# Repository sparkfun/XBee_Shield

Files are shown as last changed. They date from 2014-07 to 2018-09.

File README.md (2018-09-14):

XBee Shield
===========

<table class="table table-hover table-striped table-bordered">
  <tr align="center">
   <td><a href="https://www.sparkfun.com/products/12847">XBee Shield</a></td>
   <td><a href="https://www.sparkfun.com/products/13197">SparkFun XBee Shield Kit</a></td>
  </tr>
  <tr align="center">
    <td>XBee Shield [<a href="https://www.sparkfun.com/products/12847">WRL-12847</a>]</td>
    <td>SparkFun XBee Wireless Kit [<a href="https://www.sparkfun.com/products/13197">KIT-13197</a>]</td>
  </tr>
</table>

This shield mates directly with any dev board that has an Arduino standard footprint and equips it with the wireless
communication capabilities using the popular XBee modules. 

Repository Contents
-------------------
* **/Hardware** - All Eagle design files (.brd, .sch)
* **/Production** - Test bed files and production panel files

Documentation
--------------
* **[Exploring XBees and XCTU](https://learn.sparkfun.com/tutorials/exploring-xbees-and-xctu)** - Getting started with the XBee software and configuring XBees.
* **[Hookup Guide](https://learn.sparkfun.com/tutorials/xbee-shield-hookup-guide)** - Basic hookup guide for the XBee Shield for Arduinos.

Product Versions
----------------
* [WRL-12847](https://www.sparkfun.com/products/12847)- XBee Shield
* [KIT-13197](https://www.sparkfun.com/products/13197)- XBee Wireless Kit with XBee Series 1 Modules

Version History
---------------
* [v14](https://www.sparkfun.com/products/10854) Version 1.4. 

License Information
-------------------
License Information
-------------------

This product is _**open source**_! 

Please review the LICENSE.md file for license information. 

If you have any questions or concerns on licensing, please contact techsupport@sparkfun.com.

Distributed as-is; no warranty is given.

- Your friends at SparkFun.

_<COLLABORATION CREDIT>_

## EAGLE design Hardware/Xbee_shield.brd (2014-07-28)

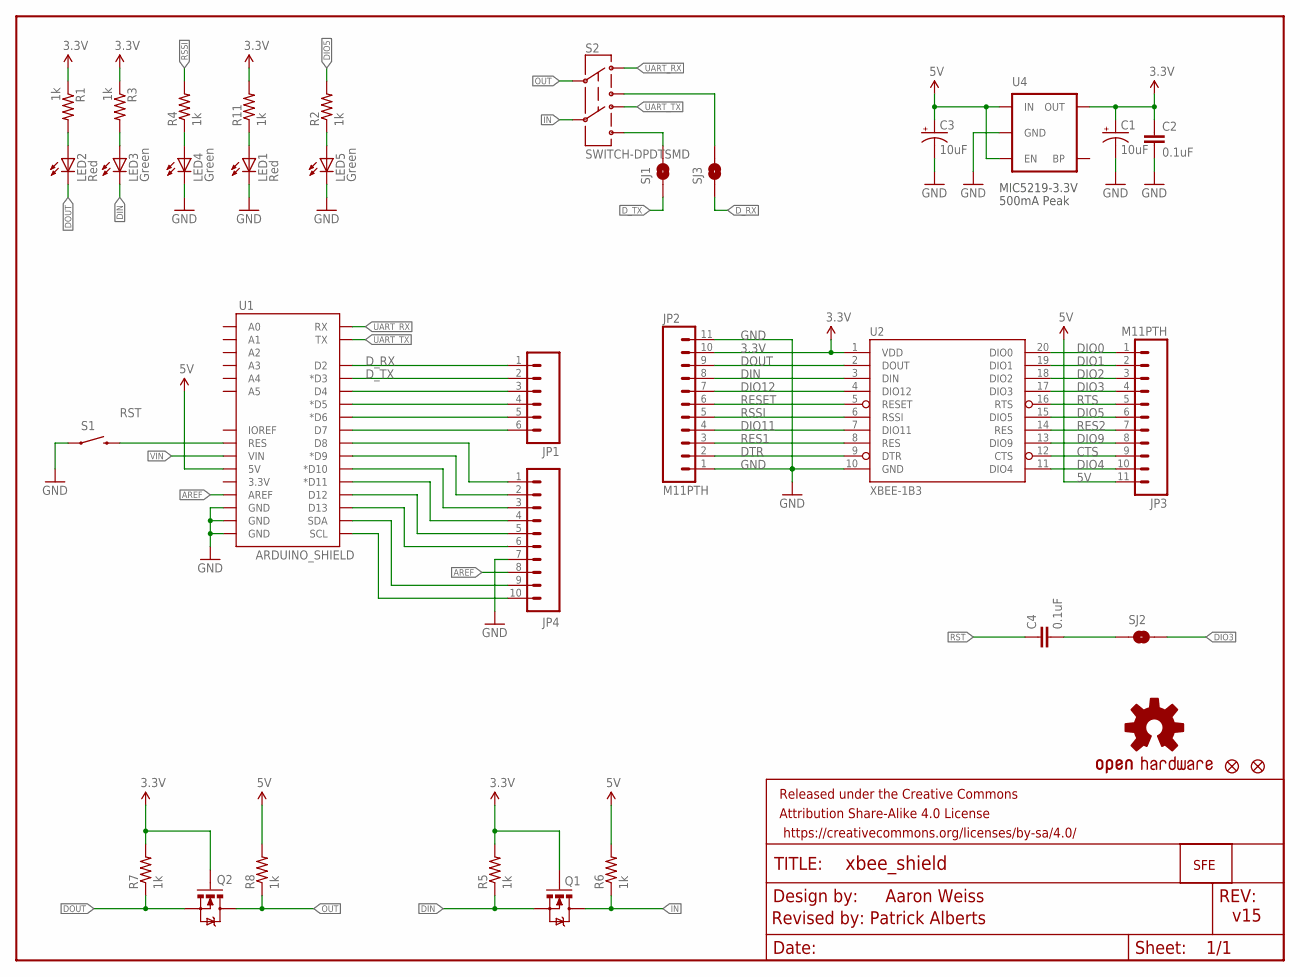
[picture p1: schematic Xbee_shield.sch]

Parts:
C1, C3: 10uF; EIA3216
C2, C4: 0.1uF; 0603-CAP
FRAME1: FRAME-LETTER; CREATIVE_COMMONS
JP1: M06SIP; 1X06
JP2, JP3: M11PTH; 1X11
JP4: M10"; 1X10
JP5, JP6: FIDUCIAL1X2; FIDUCIAL-1X2
JP7: LOGO-SFENEW; SFE-NEW-WEBLOGO
LED1, LED2: Red; LED-0603
LED3, LED4, LED5: Green; LED-0603
Q1, Q2: MOSFET-NCHANNELSMD; SOT23-3
R1, R2, R3, R4, R5, R6, R7, R8, R11: 1k; 0603-RES
S1: SWITCH-MOMENTARY-2SMD; TACTILE_SWITCH_SMD
S2: SWITCH-DPDTSMD; AYZ0202
SJ1: D_TX; SJ_2S
SJ2: SOLDERJUMPERTRACE; SJ_2S-TRACE
SJ3: D_RX; SJ_2S
U1: ARDUINO_SHIELD; UNO_R3_SHIELD
U2: XBEE-1B3; XBEE-SMD
U4: V_REG_LDOSMD; SOT23-5
U$8: OSHW-LOGOS; OSHW-LOGO-S

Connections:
3.3V: C1.A (+), C2.1, JP2.10, Q1.1 (G), Q2.1 (G), R1.1, R3.1, R5.2, R7.2, R11.2, U2.1 (VDD), U4.5 (OUT)
5V: C3.A (+), JP3.11, R6.2, R8.2, U1.5V, U4.1 (IN), U4.3 (EN)
AREF: JP4.8, U1.AREF
CTS: JP3.9, U2.12 (CTS)
DIN: JP2.8, LED3.C, Q1.2 (S), R5.1, U2.3 (DIN)
DIO0: JP3.1, U2.20 (DIO0)
DIO1: JP3.2, U2.19 (DIO1)
DIO2: JP3.3, U2.18 (DIO2)
DIO3: JP3.4, SJ2.2, U2.17 (DIO3)
DIO4: JP3.10, U2.11 (DIO4)
DIO5: JP3.6, R2.2, U2.15 (DIO5)
DIO9: JP3.8, U2.13 (DIO9)
DIO11: JP2.4, U2.7 (DIO11)
DIO12: JP2.7, U2.4 (DIO12)
DOUT: JP2.9, LED2.C, Q2.2 (S), R7.1, U2.2 (DOUT)
DTR: JP2.2, U2.9 (DTR)
D_RX: JP1.1, SJ3.1, U1.D2
D_TX: JP1.2, SJ1.1, U1.D3 (*D3)
GND: C1.C (-), C2.2, C3.C (-), JP2.1, JP2.11, JP4.7, LED1.C, LED4.C, LED5.C, S1.1, U1.GND@0 (GND), U1.GND@1 (GND), U1.GND@2 (GND), U2.10 (GND), U4.2 (GND)
IN: Q1.3 (D), R6.1, S2.5
unnamed: LED2.A, R1.2
unnamed: LED4.A, R4.1
unnamed: JP4.6, U1.D13
unnamed: LED3.A, R3.2
unnamed: C4.2, SJ2.1
unnamed: JP4.9, U1.SDA
unnamed: JP4.10, U1.SCL
unnamed: JP4.1, U1.D8
unnamed: JP4.2, U1.D9 (*D9)
unnamed: JP4.3, U1.D10 (*D10)
unnamed: LED1.A, R11.1
unnamed: JP4.4, U1.D11 (*D11)
unnamed: JP4.5, U1.D12
unnamed: LED5.A, R2.1
unnamed: S2.6, SJ1.2
unnamed: S2.3, SJ3.2
unnamed: JP1.3, U1.D4
unnamed: JP1.4, U1.D5 (*D5)
unnamed: JP1.5, U1.D6 (*D6)
unnamed: JP1.6, U1.D7
OUT: Q2.3 (D), R8.1, S2.2
RES1: JP2.3, U2.8 (RES)
RES2: JP3.7, U2.14 (RES)
RESET: JP2.6, U2.5 (RESET)
RSSI: JP2.5, R4.2, U2.6 (RSSI)
RST: C4.1, S1.3 (2), U1.RES
RTS: JP3.5, U2.16 (RTS)
UART_RX: S2.1, U1.RX
UART_TX: S2.4, U1.TX
VIN: U1.VIN

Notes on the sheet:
500mA Peak
MIC5219-3.3V
Aaron Weiss
v15
Revised by: Patrick Alberts

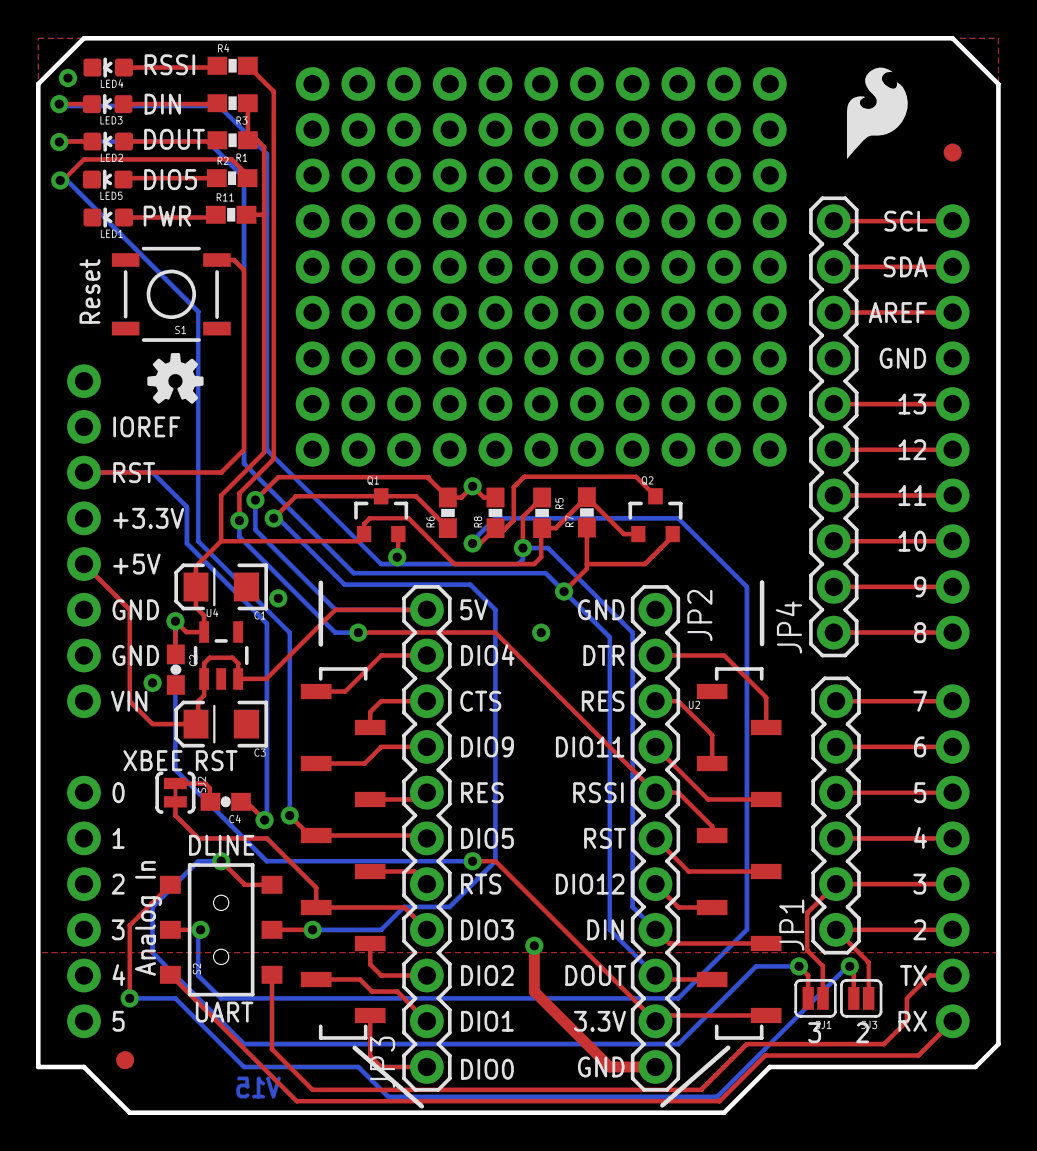
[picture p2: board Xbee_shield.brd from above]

Board: 2 copper layers, 53.3 x 59.7 mm, 38 parts (1 on the bottom side), 49 nets.

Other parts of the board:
U$1: SFE_LOGO_FLAME_.2

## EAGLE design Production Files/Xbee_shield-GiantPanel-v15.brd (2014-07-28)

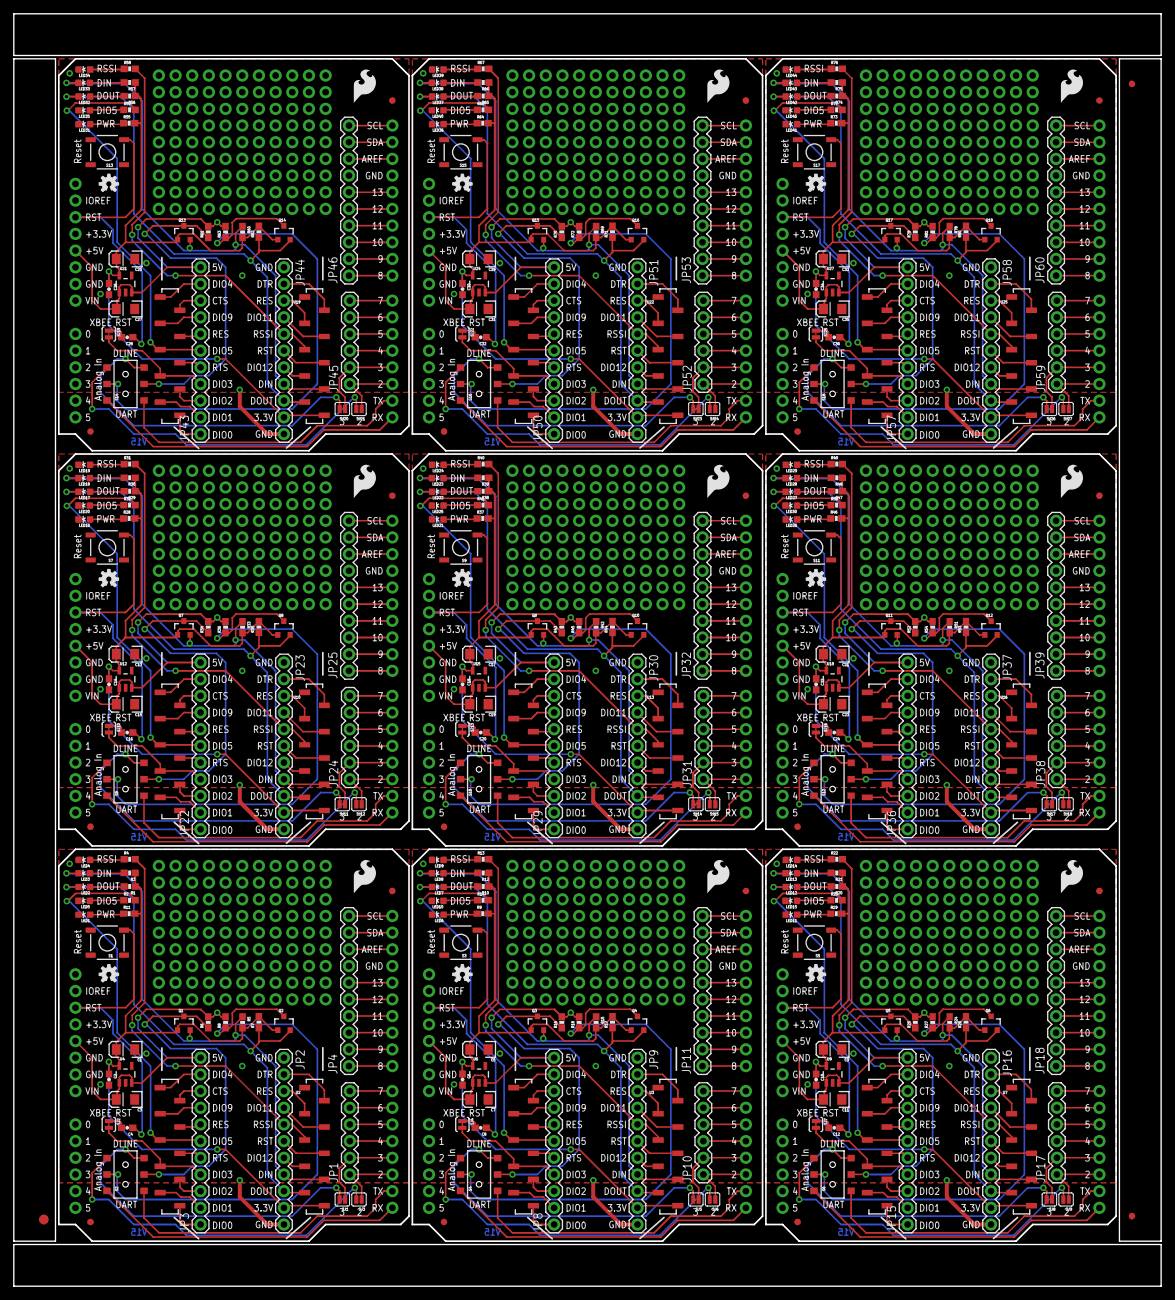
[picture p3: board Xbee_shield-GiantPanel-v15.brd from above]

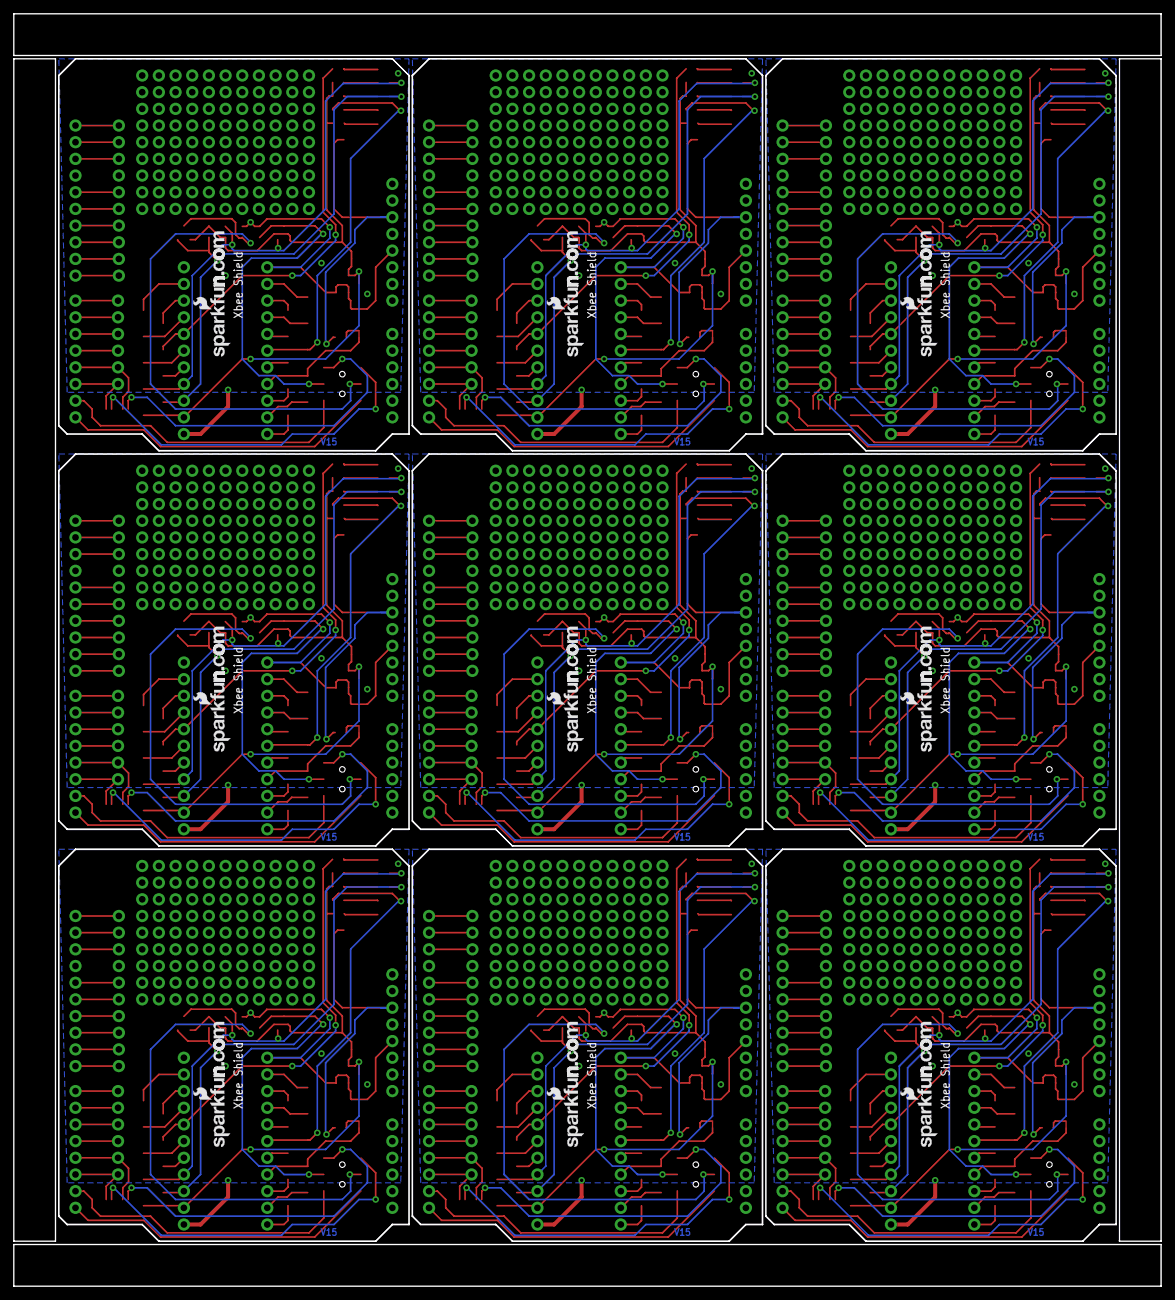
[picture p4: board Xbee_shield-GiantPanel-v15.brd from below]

Board: 2 copper layers, 174.8 x 193.8 mm, 336 parts (9 on the bottom side), 441 nets.

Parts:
C1, C3, C5, C7, C9, C11, C13, C15, C17, C19, C21, C23, C25, C27, C29, C31, C33, C35: 10uF; EIA3216
C2, C4, C6, C8, C10, C12, C14, C16, C18, C20, C22, C24, C26, C28, C30, C32, C34, C36: 0.1uF; 0603-CAP
E$1: FIDUCIAL-1.5X3
E$4, E$5: FIDUCIAL-1X2
JP1, JP10, JP17, JP24, JP31, JP38, JP45, JP52, JP59: 1X06
JP2, JP3, JP8, JP9, JP15, JP16, JP22, JP23, JP29, JP30, JP36, JP37, JP43, JP44, JP50, JP51, JP57, JP58: M11PTH; 1X11
JP4, JP11, JP18, JP25, JP32, JP39, JP46, JP53, JP60: 1X10
JP5, JP6, JP12, JP13, JP19, JP20, JP26, JP27, JP33, JP34, JP40, JP41, JP47, JP48, JP54, JP55, JP61, JP62: FIDUCIAL1X2; FIDUCIAL-1X2
JP7, JP14, JP21, JP28, JP35, JP42, JP49, JP56, JP63: LOGO-SFENEW; SFE-NEW-WEBLOGO
LED1, LED2, LED6, LED7, LED11, LED12, LED16, LED17, LED21, LED22, LED26, LED27, LED31, LED32, LED36, LED37, LED41, LED42: Red; LED-0603
LED3, LED4, LED5, LED8, LED9, LED10, LED13, LED14, LED15, LED18, LED19, LED20, LED23, LED24, LED25, LED28, LED29, LED30, LED33, LED34, LED35, LED38, LED39, LED40, LED43, LED44, LED45: Green; LED-0603
Q1, Q2, Q3, Q4, Q5, Q6, Q7, Q8, Q9, Q10, Q11, Q12, Q13, Q14, Q15, Q16, Q17, Q18: MOSFET-NCHANNELSMD; SOT23-3
R1, R2, R3, R4, R5, R6, R7, R8, R9, R10, R11, R12, R13, R14, R15, R16, R17, R18, R19, R20, R21, R22, R23, R24, R25, R26, R27, R28, R29, R30, R31, R32, R33, R34, R35, R36, R37, R38, R39, R40, R41, R42, R43, R44, R45, R46, R47, R48, R49, R50, R51, R52, R53, R54, R55, R56, R57, R58, R59, R60, R61, R62, R63, R64, R65, R66, R67, R68, R69, R70, R71, R72, R73, R74, R75, R76, R77, R78, R79, R80, R81: 1k; 0603-RES
S1, S3, S5, S7, S9, S11, S13, S15, S17: SWITCH-MOMENTARY-2SMD; TACTILE_SWITCH_SMD
S2, S4, S6, S8, S10, S12, S14, S16, S18: SWITCH-DPDTSMD; AYZ0202
SJ1, SJ5, SJ8, SJ11, SJ14, SJ17, SJ20, SJ23, SJ26: D_TX; SJ_2S
SJ2, SJ4, SJ7, SJ10, SJ13, SJ16, SJ19, SJ22, SJ25: SOLDERJUMPERTRACE; SJ_2S-TRACE
SJ3, SJ6, SJ9, SJ12, SJ15, SJ18, SJ21, SJ24, SJ27: D_RX; SJ_2S
U1, U5, U8, U11, U14, U17, U20, U23, U26: ARDUINO_SHIELD; UNO_R3_SHIELD
U2, U3, U7, U10, U13, U16, U19, U22, U25: XBEE-1B3; XBEE-SMD
U4, U6, U9, U12, U15, U18, U21, U24, U27: V_REG_LDOSMD; SOT23-5
U$1, U$3, U$5, U$7, U$10, U$12, U$14, U$16, U$18: SFE_LOGO_FLAME_.2
U$2, U$4, U$6, U$8, U$9, U$11, U$13, U$15, U$17: OSHW-LOGOS; OSHW-LOGO-S

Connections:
3.3V: C1.A, C2.1, JP2.10, Q1.1, Q2.1, R1.1, R3.1, R5.2, R7.2, R11.2, U2.1, U4.5
3.3V1: C5.A, C6.1, JP9.10, Q3.1, Q4.1, R9.2, R10.1, R12.1, R15.2, R17.2, U3.1, U6.5
3.3V2: C9.A, C10.1, JP16.10, Q5.1, Q6.1, R19.2, R20.1, R21.1, R24.2, R26.2, U7.1, U9.5
3.3V3: C13.A, C14.1, JP23.10, Q7.1, Q8.1, R28.2, R29.1, R30.1, R33.2, R35.2, U10.1, U12.5
3.3V4: C17.A, C18.1, JP30.10, Q9.1, Q10.1, R37.2, R38.1, R39.1, R42.2, R44.2, U13.1, U15.5
3.3V5: C21.A, C22.1, JP37.10, Q11.1, Q12.1, R46.2, R47.1, R48.1, R51.2, R53.2, U16.1, U18.5
3.3V6: C25.A, C26.1, JP44.10, Q13.1, Q14.1, R55.2, R56.1, R57.1, R60.2, R62.2, U19.1, U21.5
3.3V7: C29.A, C30.1, JP51.10, Q15.1, Q16.1, R64.2, R65.1, R66.1, R69.2, R71.2, U22.1, U24.5
3.3V8: C33.A, C34.1, JP58.10, Q17.1, Q18.1, R73.2, R74.1, R75.1, R78.2, R80.2, U25.1, U27.5
5V: C3.A, JP3.11, R6.2, R8.2, U1.5V, U4.1, U4.3
5V1: C7.A, JP8.11, R16.2, R18.2, U5.5V, U6.1, U6.3
5V2: C11.A, JP15.11, R25.2, R27.2, U8.5V, U9.1, U9.3
5V3: C15.A, JP22.11, R34.2, R36.2, U11.5V, U12.1, U12.3
5V4: C19.A, JP29.11, R43.2, R45.2, U14.5V, U15.1, U15.3
5V5: C23.A, JP36.11, R52.2, R54.2, U17.5V, U18.1, U18.3
5V6: C27.A, JP43.11, R61.2, R63.2, U20.5V, U21.1, U21.3
5V7: C31.A, JP50.11, R70.2, R72.2, U23.5V, U24.1, U24.3
5V8: C35.A, JP57.11, R79.2, R81.2, U26.5V, U27.1, U27.3
AREF: JP4.8, U1.AREF
AREF1: JP11.8, U5.AREF
AREF2: JP18.8, U8.AREF
AREF3: JP25.8, U11.AREF
AREF4: JP32.8, U14.AREF
AREF5: JP39.8, U17.AREF
AREF6: JP46.8, U20.AREF
AREF7: JP53.8, U23.AREF
AREF8: JP60.8, U26.AREF
CTS: JP3.9, U2.12
CTS1: JP8.9, U3.12
CTS2: JP15.9, U7.12
CTS3: JP22.9, U10.12
CTS4: JP29.9, U13.12
CTS5: JP36.9, U16.12
CTS6: JP43.9, U19.12
CTS7: JP50.9, U22.12
CTS8: JP57.9, U25.12
DIN: JP2.8, LED3.C, Q1.2, R5.1, U2.3
DIN1: JP9.8, LED8.C, Q3.2, R15.1, U3.3
DIN2: JP16.8, LED13.C, Q5.2, R24.1, U7.3
DIN3: JP23.8, LED18.C, Q7.2, R33.1, U10.3
DIN4: JP30.8, LED23.C, Q9.2, R42.1, U13.3
DIN5: JP37.8, LED28.C, Q11.2, R51.1, U16.3
DIN6: JP44.8, LED33.C, Q13.2, R60.1, U19.3
DIN7: JP51.8, LED38.C, Q15.2, R69.1, U22.3
DIN8: JP58.8, LED43.C, Q17.2, R78.1, U25.3
DIO0: JP3.1, U2.20
DIO1: JP3.2, U2.19
DIO2: JP3.3, U2.18
DIO3: JP3.4, SJ2.2, U2.17
DIO4: JP3.10, U2.11
DIO5: JP3.6, R2.2, U2.15
DIO6: JP8.10, U3.11
DIO7: JP8.8, U3.13
DIO8: JP8.6, R14.2, U3.15
DIO9: JP3.8, U2.13
DIO10: JP8.4, SJ4.2, U3.17
DIO11: JP2.4, U2.7
DIO12: JP2.7, U2.4
DIO13: JP8.3, U3.18
DIO14: JP8.2, U3.19
DIO15: JP8.1, U3.20
DIO16: JP9.4, U3.7
DIO17: JP9.7, U3.4
DIO18: JP15.10, U7.11
DIO19: JP15.8, U7.13
DIO20: JP15.6, R23.2, U7.15
DIO21: JP15.4, SJ7.2, U7.17
DIO22: JP15.3, U7.18
DIO23: JP15.2, U7.19
DIO24: JP15.1, U7.20
DIO25: JP16.4, U7.7
DIO26: JP16.7, U7.4
DIO27: JP22.10, U10.11
DIO28: JP22.8, U10.13
DIO29: JP22.6, R32.2, U10.15
DIO30: JP22.4, SJ10.2, U10.17
DIO31: JP22.3, U10.18
DIO32: JP22.2, U10.19
DIO33: JP22.1, U10.20
DIO34: JP23.4, U10.7
DIO35: JP23.7, U10.4
DIO36: JP29.10, U13.11
DIO37: JP29.8, U13.13
DIO38: JP29.6, R41.2, U13.15
DIO39: JP29.4, SJ13.2, U13.17
DIO40: JP29.3, U13.18
DIO41: JP29.2, U13.19
DIO42: JP29.1, U13.20
DIO43: JP30.4, U13.7
DIO44: JP30.7, U13.4
DIO45: JP36.10, U16.11
DIO46: JP36.8, U16.13
DIO47: JP36.6, R50.2, U16.15
DIO48: JP36.4, SJ16.2, U16.17
DIO49: JP36.3, U16.18
DIO50: JP36.2, U16.19
DIO51: JP36.1, U16.20
DIO52: JP37.4, U16.7
DIO53: JP37.7, U16.4
DIO54: JP43.10, U19.11
DIO55: JP43.8, U19.13
DIO56: JP43.6, R59.2, U19.15
DIO57: JP43.4, SJ19.2, U19.17
DIO58: JP43.3, U19.18
DIO59: JP43.2, U19.19
DIO60: JP43.1, U19.20
DIO61: JP44.4, U19.7
DIO62: JP44.7, U19.4
DIO63: JP50.10, U22.11
DIO64: JP50.8, U22.13
DIO65: JP50.6, R68.2, U22.15
DIO66: JP50.4, SJ22.2, U22.17
DIO67: JP50.3, U22.18
DIO68: JP50.2, U22.19
DIO69: JP50.1, U22.20
DIO70: JP51.4, U22.7
DIO71: JP51.7, U22.4
DIO72: JP57.10, U25.11
DIO73: JP57.8, U25.13
DIO74: JP57.6, R77.2, U25.15
DIO75: JP57.4, SJ25.2, U25.17
DIO76: JP57.3, U25.18
DIO77: JP57.2, U25.19
DIO78: JP57.1, U25.20
DIO79: JP58.4, U25.7
DIO80: JP58.7, U25.4
DOUT: JP2.9, LED2.C, Q2.2, R7.1, U2.2
DOUT1: JP9.9, LED7.C, Q4.2, R17.1, U3.2
DOUT2: JP16.9, LED12.C, Q6.2, R26.1, U7.2
DOUT3: JP23.9, LED17.C, Q8.2, R35.1, U10.2
DOUT4: JP30.9, LED22.C, Q10.2, R44.1, U13.2
DOUT5: JP37.9, LED27.C, Q12.2, R53.1, U16.2
DOUT6: JP44.9, LED32.C, Q14.2, R62.1, U19.2
DOUT7: JP51.9, LED37.C, Q16.2, R71.1, U22.2
DOUT8: JP58.9, LED42.C, Q18.2, R80.1, U25.2
DTR: JP2.2, U2.9
DTR1: JP9.2, U3.9
DTR2: JP16.2, U7.9
DTR3: JP23.2, U10.9
DTR4: JP30.2, U13.9
DTR5: JP37.2, U16.9
DTR6: JP44.2, U19.9
DTR7: JP51.2, U22.9
DTR8: JP58.2, U25.9
D_RX: JP1.1, SJ3.1, U1.D2
D_RX1: JP10.1, SJ6.1, U5.D2
D_RX2: JP17.1, SJ9.1, U8.D2
D_RX3: JP24.1, SJ12.1, U11.D2
D_RX4: JP31.1, SJ15.1, U14.D2
D_RX5: JP38.1, SJ18.1, U17.D2
D_RX6: JP45.1, SJ21.1, U20.D2
D_RX7: JP52.1, SJ24.1, U23.D2
D_RX8: JP59.1, SJ27.1, U26.D2
D_TX: JP1.2, SJ1.1, U1.D3
D_TX1: JP10.2, SJ5.1, U5.D3
D_TX2: JP17.2, SJ8.1, U8.D3
D_TX3: JP24.2, SJ11.1, U11.D3
D_TX4: JP31.2, SJ14.1, U14.D3
D_TX5: JP38.2, SJ17.1, U17.D3
D_TX6: JP45.2, SJ20.1, U20.D3
D_TX7: JP52.2, SJ23.1, U23.D3
D_TX8: JP59.2, SJ26.1, U26.D3
GND: C1.C, C2.2, C3.C, JP2.1, JP2.11, JP4.7, LED1.C, LED4.C, LED5.C, S1.1, U1.GND@0, U1.GND@1, U1.GND@2, U2.10, U4.2
GND1: C5.C, C6.2, C7.C, JP9.1, JP9.11, JP11.7, LED6.C, LED9.C, LED10.C, S3.1, U3.10, U5.GND@0, U5.GND@1, U5.GND@2, U6.2
GND2: C9.C, C10.2, C11.C, JP16.1, JP16.11, JP18.7, LED11.C, LED14.C, LED15.C, S5.1, U7.10, U8.GND@0, U8.GND@1, U8.GND@2, U9.2
GND3: C13.C, C14.2, C15.C, JP23.1, JP23.11, JP25.7, LED16.C, LED19.C, LED20.C, S7.1, U10.10, U11.GND@0, U11.GND@1, U11.GND@2, U12.2
GND4: C17.C, C18.2, C19.C, JP30.1, JP30.11, JP32.7, LED21.C, LED24.C, LED25.C, S9.1, U13.10, U14.GND@0, U14.GND@1, U14.GND@2, U15.2
GND5: C21.C, C22.2, C23.C, JP37.1, JP37.11, JP39.7, LED26.C, LED29.C, LED30.C, S11.1, U16.10, U17.GND@0, U17.GND@1, U17.GND@2, U18.2
GND6: C25.C, C26.2, C27.C, JP44.1, JP44.11, JP46.7, LED31.C, LED34.C, LED35.C, S13.1, U19.10, U20.GND@0, U20.GND@1, U20.GND@2, U21.2
GND7: C29.C, C30.2, C31.C, JP51.1, JP51.11, JP53.7, LED36.C, LED39.C, LED40.C, S15.1, U22.10, U23.GND@0, U23.GND@1, U23.GND@2, U24.2
GND8: C33.C, C34.2, C35.C, JP58.1, JP58.11, JP60.7, LED41.C, LED44.C, LED45.C, S17.1, U25.10, U26.GND@0, U26.GND@1, U26.GND@2, U27.2
IN: Q1.3, R6.1, S2.5
IN1: Q3.3, R16.1, S4.5
IN2: Q5.3, R25.1, S6.5
IN3: Q7.3, R34.1, S8.5
IN4: Q9.3, R43.1, S10.5
IN5: Q11.3, R52.1, S12.5
IN6: Q13.3, R61.1, S14.5
IN7: Q15.3, R70.1, S16.5
IN8: Q17.3, R79.1, S18.5
unnamed: LED2.A, R1.2
unnamed: LED4.A, R4.1
unnamed: JP4.6, U1.D13
unnamed: LED3.A, R3.2
unnamed: C4.2, SJ2.1
unnamed: JP4.9, U1.SDA
unnamed: JP4.10, U1.SCL
unnamed: LED6.A, R9.1
unnamed: LED7.A, R10.2
unnamed: LED8.A, R12.2
unnamed: LED9.A, R13.1
unnamed: C8.2, SJ4.1
unnamed: JP4.1, U1.D8
unnamed: JP4.2, U1.D9
unnamed: JP4.3, U1.D10
unnamed: LED1.A, R11.1
unnamed: JP4.4, U1.D11
unnamed: JP4.5, U1.D12
unnamed: LED5.A, R2.1
unnamed: S2.6, SJ1.2
unnamed: S2.3, SJ3.2
unnamed: JP1.3, U1.D4
unnamed: JP1.4, U1.D5
unnamed: JP1.5, U1.D6
unnamed: JP1.6, U1.D7
unnamed: LED10.A, R14.1
unnamed: S4.6, SJ5.2
unnamed: S4.3, SJ6.2
unnamed: JP10.3, U5.D4
unnamed: JP10.4, U5.D5
unnamed: JP10.5, U5.D6
unnamed: JP10.6, U5.D7
unnamed: JP11.1, U5.D8
unnamed: JP11.2, U5.D9
unnamed: JP11.3, U5.D10
unnamed: JP11.4, U5.D11
unnamed: JP11.5, U5.D12
unnamed: JP11.6, U5.D13
unnamed: JP11.9, U5.SDA
unnamed: JP11.10, U5.SCL
unnamed: LED11.A, R19.1
unnamed: LED12.A, R20.2
unnamed: LED13.A, R21.2
unnamed: LED14.A, R22.1
unnamed: C12.2, SJ7.1
unnamed: LED15.A, R23.1
unnamed: S6.6, SJ8.2
unnamed: S6.3, SJ9.2
unnamed: JP17.3, U8.D4
unnamed: JP17.4, U8.D5
unnamed: JP17.5, U8.D6
unnamed: JP17.6, U8.D7
unnamed: JP18.1, U8.D8
unnamed: JP18.2, U8.D9
unnamed: JP18.3, U8.D10
unnamed: JP18.4, U8.D11
unnamed: JP18.5, U8.D12
unnamed: JP18.6, U8.D13
unnamed: JP18.9, U8.SDA
unnamed: JP18.10, U8.SCL
unnamed: LED16.A, R28.1
unnamed: LED17.A, R29.2
unnamed: LED18.A, R30.2
unnamed: LED19.A, R31.1
unnamed: C16.2, SJ10.1
unnamed: LED20.A, R32.1
unnamed: S8.6, SJ11.2
unnamed: S8.3, SJ12.2
unnamed: JP24.3, U11.D4
unnamed: JP24.4, U11.D5
unnamed: JP24.5, U11.D6
unnamed: JP24.6, U11.D7
unnamed: JP25.1, U11.D8
unnamed: JP25.2, U11.D9
unnamed: JP25.3, U11.D10
unnamed: JP25.4, U11.D11
unnamed: JP25.5, U11.D12
unnamed: JP25.6, U11.D13
unnamed: JP25.9, U11.SDA
unnamed: JP25.10, U11.SCL
unnamed: LED21.A, R37.1
unnamed: LED22.A, R38.2
unnamed: LED23.A, R39.2
unnamed: LED24.A, R40.1
unnamed: C20.2, SJ13.1
unnamed: LED25.A, R41.1
unnamed: S10.6, SJ14.2
unnamed: S10.3, SJ15.2
unnamed: JP31.3, U14.D4
unnamed: JP31.4, U14.D5
unnamed: JP31.5, U14.D6
unnamed: JP31.6, U14.D7
unnamed: JP32.1, U14.D8
unnamed: JP32.2, U14.D9
unnamed: JP32.3, U14.D10
unnamed: JP32.4, U14.D11
unnamed: JP32.5, U14.D12
unnamed: JP32.6, U14.D13
unnamed: JP32.9, U14.SDA
unnamed: JP32.10, U14.SCL
unnamed: LED26.A, R46.1
unnamed: LED27.A, R47.2
unnamed: LED28.A, R48.2
unnamed: LED29.A, R49.1
unnamed: C24.2, SJ16.1
unnamed: LED30.A, R50.1
unnamed: S12.6, SJ17.2
unnamed: S12.3, SJ18.2
unnamed: JP38.3, U17.D4
unnamed: JP38.4, U17.D5
unnamed: JP38.5, U17.D6
unnamed: JP38.6, U17.D7
unnamed: JP39.1, U17.D8
unnamed: JP39.2, U17.D9
unnamed: JP39.3, U17.D10
unnamed: JP39.4, U17.D11
unnamed: JP39.5, U17.D12
unnamed: JP39.6, U17.D13
unnamed: JP39.9, U17.SDA
unnamed: JP39.10, U17.SCL
unnamed: LED31.A, R55.1
unnamed: LED32.A, R56.2
unnamed: LED33.A, R57.2
unnamed: LED34.A, R58.1
unnamed: C28.2, SJ19.1
unnamed: LED35.A, R59.1
unnamed: S14.6, SJ20.2
unnamed: S14.3, SJ21.2
unnamed: JP45.3, U20.D4
unnamed: JP45.4, U20.D5
unnamed: JP45.5, U20.D6
unnamed: JP45.6, U20.D7
unnamed: JP46.1, U20.D8
unnamed: JP46.2, U20.D9
unnamed: JP46.3, U20.D10
unnamed: JP46.4, U20.D11
unnamed: JP46.5, U20.D12
unnamed: JP46.6, U20.D13
unnamed: JP46.9, U20.SDA
unnamed: JP46.10, U20.SCL
unnamed: LED36.A, R64.1
unnamed: LED37.A, R65.2
unnamed: LED38.A, R66.2
unnamed: LED39.A, R67.1
unnamed: C32.2, SJ22.1
unnamed: LED40.A, R68.1
unnamed: S16.6, SJ23.2
unnamed: S16.3, SJ24.2
unnamed: JP52.3, U23.D4
unnamed: JP52.4, U23.D5
unnamed: JP52.5, U23.D6
unnamed: JP52.6, U23.D7
unnamed: JP53.1, U23.D8
unnamed: JP53.2, U23.D9
unnamed: JP53.3, U23.D10
unnamed: JP53.4, U23.D11
unnamed: JP53.5, U23.D12
unnamed: JP53.6, U23.D13
unnamed: JP53.9, U23.SDA
unnamed: JP53.10, U23.SCL
unnamed: LED41.A, R73.1
unnamed: LED42.A, R74.2
unnamed: LED43.A, R75.2
unnamed: LED44.A, R76.1
unnamed: C36.2, SJ25.1
unnamed: LED45.A, R77.1
unnamed: S18.6, SJ26.2
unnamed: S18.3, SJ27.2
unnamed: JP59.3, U26.D4
unnamed: JP59.4, U26.D5
unnamed: JP59.5, U26.D6
unnamed: JP59.6, U26.D7
unnamed: JP60.1, U26.D8
unnamed: JP60.2, U26.D9
unnamed: JP60.3, U26.D10
unnamed: JP60.4, U26.D11
unnamed: JP60.5, U26.D12
unnamed: JP60.6, U26.D13
unnamed: JP60.9, U26.SDA
unnamed: JP60.10, U26.SCL
OUT: Q2.3, R8.1, S2.2
OUT1: Q4.3, R18.1, S4.2
OUT2: Q6.3, R27.1, S6.2
OUT3: Q8.3, R36.1, S8.2
OUT4: Q10.3, R45.1, S10.2
OUT5: Q12.3, R54.1, S12.2
OUT6: Q14.3, R63.1, S14.2
OUT7: Q16.3, R72.1, S16.2
OUT8: Q18.3, R81.1, S18.2
RES1: JP2.3, U2.8
RES2: JP3.7, U2.14
RES3: JP9.3, U3.8
RES4: JP8.7, U3.14
RES5: JP16.3, U7.8
RES6: JP15.7, U7.14
RES7: JP23.3, U10.8
RES8: JP22.7, U10.14
RES9: JP30.3, U13.8
RES10: JP29.7, U13.14
RES11: JP37.3, U16.8
RES12: JP36.7, U16.14
RES13: JP44.3, U19.8
RES14: JP43.7, U19.14
RES15: JP51.3, U22.8
RES16: JP50.7, U22.14
RES17: JP58.3, U25.8
RES18: JP57.7, U25.14
RESET: JP2.6, U2.5
RESET1: JP9.6, U3.5
RESET2: JP16.6, U7.5
RESET3: JP23.6, U10.5
RESET4: JP30.6, U13.5
RESET5: JP37.6, U16.5
RESET6: JP44.6, U19.5
RESET7: JP51.6, U22.5
RESET8: JP58.6, U25.5
RSSI: JP2.5, R4.2, U2.6
RSSI1: JP9.5, R13.2, U3.6
RSSI2: JP16.5, R22.2, U7.6
RSSI3: JP23.5, R31.2, U10.6
RSSI4: JP30.5, R40.2, U13.6
RSSI5: JP37.5, R49.2, U16.6
RSSI6: JP44.5, R58.2, U19.6
RSSI7: JP51.5, R67.2, U22.6
RSSI8: JP58.5, R76.2, U25.6
RST: C4.1, S1.3, U1.RES
RST1: C8.1, S3.3, U5.RES
RST2: C12.1, S5.3, U8.RES
RST3: C16.1, S7.3, U11.RES
RST4: C20.1, S9.3, U14.RES
RST5: C24.1, S11.3, U17.RES
RST6: C28.1, S13.3, U20.RES
RST7: C32.1, S15.3, U23.RES
RST8: C36.1, S17.3, U26.RES
RTS: JP3.5, U2.16
RTS1: JP8.5, U3.16
RTS2: JP15.5, U7.16
RTS3: JP22.5, U10.16
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

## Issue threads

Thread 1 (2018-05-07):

Power On/Off with a Digital Pin

dorkmo, 2018-05-07:
In the next version of the board, I think it would be nice if there was a soldered jumper after the 5V header hole that could be removed, then maybe two 0.1" holes on either side of the jumper so that a transistor could be installed in the protoyping area and then be triggered by an arduino digital pin to supply 5V as usual.

dorkmo, 2018-05-07:
I think a solderable jumper after the 5V header would actually be all that is needed. Could remove, then jumper wire to the protype area, then supply 5V to the 5V 0.1 hole below the xbee mounting area. I think i might just cut the lead. nice. thanks.

Closed 2018-05-07.

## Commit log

2013-09-23 Initial Commit
    Initial commit with Readme and Gitignore
    [Xbee_shield.brd, Xbee_shield.sch]
2014-03-13 Updates to res/caps/r3 sheild, trace re routes
    [Xbee_shield.brd, Xbee_shield.sch]
2014-03-13 Fixed LED's/Silk
    [Xbee_shield.brd, Xbee_shield.sch]
2014-03-14 Sch work
    [Xbee_shield.brd, Xbee_shield.sch]
2014-03-20 Changes to Silk/SCH
    [Xbee_shield.brd, Xbee_shield.sch]
2014-04-01 Updated Silk
    Fixed spelling error
    [Xbee_shield.brd]
2014-04-05 created v15 giant panel
    [Xbee_shield-GiantPanel-v15.brd]

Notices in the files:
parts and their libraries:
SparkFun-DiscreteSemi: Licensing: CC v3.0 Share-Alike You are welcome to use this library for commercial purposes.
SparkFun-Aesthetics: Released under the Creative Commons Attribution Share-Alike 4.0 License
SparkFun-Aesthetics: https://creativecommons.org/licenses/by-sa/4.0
